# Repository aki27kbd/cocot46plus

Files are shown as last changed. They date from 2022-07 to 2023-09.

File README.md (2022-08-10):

# cocot46plus

cocot46plus_main15

cocot46plus is a column staggered keyboard with 46 keys, a 34mm-trackball and a rotary encoder.

- Keyboard Maintainer: [aki27kbd](https://github.com/aki27kbd) [@aki27kbd](https://twitter.com/aki27kbd)
- Hardware Supported: cocot46plus PCB, ProMicro
- Hardware Availability: [BOOTH](https://aki27.booth.pm/items/3879034)
  Go on sale in June 2022.

The detail information is available from the link below:  
[JP](https://www.notion.so/aki27/cocot46plus-55775bf44a664dae9d6ca342e79e8312) / [EN](https://aki27.notion.site/cocot46plus-Introduction-e6261b0a5ce045f8a0d8535a74844929)

[Firmware](https://github.com/aki27kbd/qmk_firmware/tree/master/keyboards/cocot46plus)

Build Guide [JP](doc/buildguide.md) / [EN](doc/buildguide_en.md)

### Special keycodes

Value    | Keycode   |Description
---------|-----------|-----------
`0x5DA7` | `CPI_SW`  |Switch CPI
`0x5DA8` | `SCRL_SW` |Switch scroll divider
`0x5DA9` | `ROT_R15` |Rotate sensor coordinate by 15 degrees clockwise
`0x5DAA` | `ROT_L15` |Rotate sensor coordinate by 15 degrees counterclockwise
`0x5DAB` | `SCRL_MO` |Enable scroll mode while being pressed
`0x5DAC` | `SCRL_TO` |Toggle scroll mode. Once pushed, mouse mode and scroll mode are switched.
`0x5DAD` | `SCRL_IN` |Invert scroll direction

### Gallery

cocot46plus_main12

cocot46plus_main14

cocot46plus_main05

cocot46plus_main02

cocot46plus_main10

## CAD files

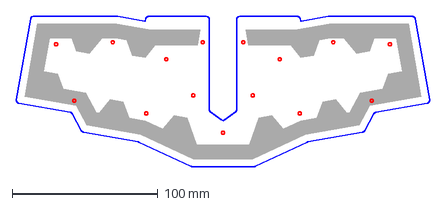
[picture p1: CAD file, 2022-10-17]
hardware/cocot46plus_acrylic_bottom.dxf
283.2 x 102.9 mm

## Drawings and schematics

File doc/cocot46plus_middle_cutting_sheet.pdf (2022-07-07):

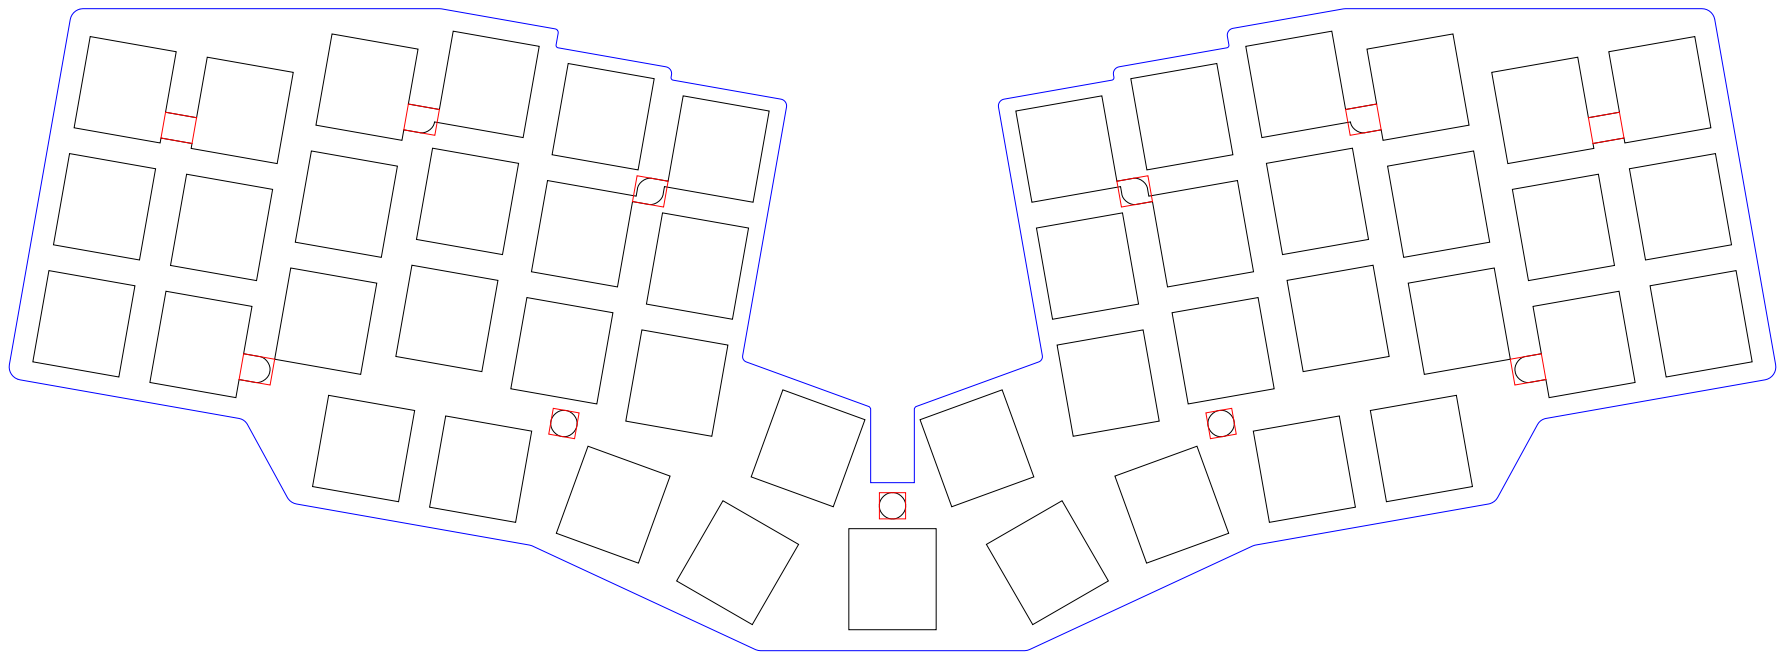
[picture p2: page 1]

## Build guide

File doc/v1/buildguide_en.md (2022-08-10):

# Build Guide

cocot46plus_main15

This is a build guide for cocot46plus.
One feature of cocot46plus is that it has a 34mm trackball in the center.
It also has a rotary encoder in the center between the thumb keys, allowing the encoder to be operated with both thumbs without disrupting the home position.
The OLED at the top can display current layer information and trackball status (CPI, rotary axis angle, etc.).
Other options include an acrylic laminated case, which can be mounted according to your preference.

## Parts
### Kit Accessories

|Switch_Plate|PCB PCB_v2|Bottom_Acryl|Bottom_FR4|
|---|---|---|---|
|Switch plate (FR4) x 1 piece|Pre-mounted PCB x 1 piece(may have tabs depending on the sales period)|Bottom plate➀ (Acrylic) x 1 piece(design may vary depending on the sales period)|Bottom plate➁ (FR4) x 1 piece|
|OLED_Cover|Spacer_8mm|Spacer_6mm|Spacer_3mm|
|OLED cover plate (FR4) x 1 piece|M2 spacer 8mm (female - female) x 15pcs|M2 spacer 6mm (female - female) x 4pcs|M2 spacer 3mm (female - male) x 4pcs|
|Screw_3mm|Screw_5mm|Screw_8mm|SwitchSocket|
|M2 Screw 3mm x 19pcs|M2 Screw 5mm x 15pcs|M2 Screw 8mm x 4pcs|Kailh MX Hotswap sockets x 46pcs|
|ADNS5050|SensorLED|OLED|ResetSwitch|
|Mouse sensor (ADNS-5050) and lens x 1 piece|LED for mouse sensor x 1 piece|OLED module, pin socket and pin header x 1 piece|Tact switch x 1 piece|
|RotaryEncoder|SK6812MINI-E|Rubber Feet||
|Rotary encoder (EC12 compatible) x 1 piece|RGB LED (SK6812MINI-E) x 2 pcs|Rubber feet x 6 pcs||

### Ball Case Accessories

|Ballcase_34mm|Ballcase_25mm|
|---|---|
|34mm ballcase (top and bottom) x 1 piece|25mm ballcase (top and bottom) and 25mm ball x 1 piece|

### Additional required parts

The following parts can be obtained from [Yousha Kobo](https://shop.yushakobo.jp/), [TALP KEYBOARD](https://talpkeyboard.net/), [Daily Craft Keyboard](https://shop.dailycraft.jp/), etc. 22mm diameter knobs are available at [Hechoamano Kobo @ Taneyatsu Branch](https://booth.pm/ja/items/3944829).

|Name|Number|Remarks|
|---|---|---|
|MicroUSB or USB-TypeC cable|1 piece||
|ProMicro or compatible microcontroller|1 piece||
|Header pins(2.5mm x 12pin)|2 pcs||
|46 switches|46pcs|MX compatible||
|46 keycaps (1U)|46pcs|MX compatible
|1 rotary encoder knob|1piece|22mm max. diameter or less
|34mm trackball|1piece|34mm ball case if selected|

*Sensor performance depends on the color of the trackball.  
*To improve the sensor performance of other ball colors a [modification](#Optional-mod) is available.  
*[Added on 8/8/2022] For boards with ver1.1 or later, [following mod](#Optional-mod) has already been implemented in default. The default performance is still the same, but the response of balls with darker colors such as green, black, etc. is also improved.

|Reactivity|Color|
|---|---|
|Good (smooth operation possible)|Red, Purple, Silver, Gold, Gray, Yellow, Pink, Lavender|
|Not good (The angle of the LED may make it a little less responsive, better to implement the modification)|Blue, Green||
|Worse (No response or stutter, need the modification)|Black|

### Optional parts (acrylic case)

Acrylic plates can be ordered with laser cutting services such as Yusha Kobo or Anymany for acrylic plates in your favorite colors.

Silicon sheets can be purchased from [here](https://www.monotaro.com/p/3629/5253/).

|Name|Number|Remarks|
|---|---|---|
|Acrylic middle plate (top)|1|for acrylic case
|Acrylic middle plate (bottom)|1|for acrylic case
|Silicon sheet 0.5mm thick|1|for acrylic case

## Assembly
### 0. Parts Check

  First, check that all the parts listed in the kit accessories are present.  
  Please prepare the kit with the above-mentioned "Additional required parts" and "optional parts" before starting the assembly.

  - If the PCB has tabs, break off the tabs and file the cut surface lightly.
  - Paint the sides of the PCB and switch plate black with an oil-based marker to make them look better. Please give it a try.

  Top: painted / Bottom: unpainted  
  cocot46plus_bg_00

### 1. Diodes

  Since ver1.0 or later, the diodes come pre-soldered on the board, so soldering the diodes is not necessary.

### Indicator LEDs

  Solder the indicator LEDs in two places beside the microcontroller. LEDs are very sensitive to heat, so set the soldering iron to a low temperature and wait long enough after soldering one pin before soldering the next.  
  At this stage, prepare the firmware described below and check the LEDs one by one as you solder, to confirm the leds are properly soldered at an early stage.
  With the default firmware, the indicator LEDs do not light up on the base layer. When checking the lighting, short the SW39 or SW44 pads with tweezers, to perform a layer switch and check the leds.

  cocot46plus_bg_02_1

  cocot46plus_bg_02_2

### 3. Underglow LED

  Since ver1.0 or later, the underglow LEDs come pre-soldered on the board, so soldering the underglow LEDs is not necessary.

### 4. Microcontroller

  Prepare the microcontroller. Solder the header pins in the orientation shown in the photo. In this case we are using spring loaded header pins. Note that these have an orientation. For more information about the direction of these pins, see [here](https://yushakobo.zendesk.com/hc/ja/articles/360044233974-%E3%82%B3%E3%83%B3%E3%82%B9%E3%83%AB%E3%83%BC-%E3%82%B9%E3%83%97%E3%83%AA%E3%83%B3%E3%82%B0%E3%83%94%E3%83%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)).  
  The USB Type-C version of a ProMicro is also supported. In case of micro USB, please reinforce the USB connector before soldering as it is prone to breaking off.

  cocot46plus_bg_04_1

### 5. mouse sensor

#### 5-1. ADNS-5050
  Place the mouse sensor (ADNS-5050) from the backside of the board in the orientation shown in the photo and solder from the topside.   
  ***Make sure to align the ●● mark on the silkscreen with the ●● mark on the board.***  
  cocot46plus_bg_05_1

  With the sensor legs firmly in place, secure them with masking tape or other means so that they stay in place.  
  cocot46plus_bg_05_2

  Solder the 8 legs from the topside.  
  cocot46plus_bg_05_3

  Remove the tape on the sensor, place the lens from the topside and fix it with masking tape, etc.  
  cocot46plus_bg_05_4

#### 5-2. Sensor LED

  Attach the LED for the mouse sensor. Pass the legs of the LED through the backside of the board. Pass the long leg through the round hole and the short leg through the square hole.  
  cocot46plus_bg_05_5

  Bend the LED legs 90 degrees and fix them with masking tape or similar so that they are positioned as shown in the photo below when viewed from the side.  
  cocot46plus_bg_05_5_2

  Solder two LED legs from the topside and trim the legs with flush cutters.  
  cocot46plus_bg_05_6

#### 5-3. Jumpers

  Bridge the pads on the back side of the board.
  cocot46plus_bg_05_7

  cocot46plus_bg_05_8

  Once you have completed this step, flash the firmware mentioned below and check the operation. If you have followed the steps correctly, a total of 12 LEDs and the LED for the mouse sensor should be lit.  
  ***The latest firmware supports LED1 & 2 as indicators. They are lit only when the layer is moved from the default.***
  cocot46plus_bg_05_9a

  Hold your hand in front of the lens on the top side and check if the mouse cursor is moving.  
  cocot46plus_bg_05_9b

### 6. MX sockets

  Solder the sockets on the back side of the PCB as shown in the picture. **Solder in all 46 locations**.

  cocot46plus_bg_06_1

### 7. OLED

  Insert the OLED pin socket from the front side and secure it with masking tape.  
  cocot46plus_bg_07_1

  cocot46plus_bg_07_2

  Solder the four pin socket legs from the backside of the board.  
  cocot46plus_bg_07_3

  Pass the pin headers through the OLED module and solder one by one so that they are not slanted.  
  cocot46plus_bg_07_4

### 8. Tact switch

  Insert the tact switch (reset switch) from the top side of the PCB and solder from the back side.  
  cocot46plus_bg_08_1

### 9. Rotary Encoder

  Solder the rotary encoder to the lower center section. Solder the rotary encoder from the back side.  
  cocot46plus_bg_09_1

  cocot46plus_bg_09_2

  All parts are finished being attached.  
  cocot46plus_bg_09_3

  cocot46plus_bg_09_4

### 10. Assembly

  To be updated.
  Secure the 8mm spacer to the bottom plate (acrylic) with 5mm screws.  
  cocot46plus_bg_10_1

  Place the bottom plate (FR4) over the back side (bottom side) of the acrylic plate and secure the 3mm spacer (female-male) with 5mm screws.  
  cocot46plus_bg_10_2

  Secure the 8mm spacer on the board with 3mm screws. Also insert the OLED into the pin socket.  
  cocot46plus_bg_10_3

  Place the switch plate and the board on top of each other and insert the key switches starting from the corners. Be careful to orient the switches and also make sure to insert them straight so that the switch legs do not bend.  
  cocot46plus_bg_10_4

  All keyswitches are inserted.  
  cocot46plus_bg_10_5

  Place the switch plate & board with the switches inserted on top of the bottom plate. Place 6mm spacers on the 4 places around the trackball.  
  cocot46plus_bg_10_6

  Secure the switch plate with 3mm screws.  
  cocot46plus_bg_10_7

  Secure the OLED cover plate with 3mm screws.  
  cocot46plus_bg_10_8

  Put the corresponding ball in the trackball case and secure it with 8mm screws.  
  cocot46plus_bg_10_9

  Attach the rubber feet to the bottom plate as shown.  
  cocot46plus_bg_10_10

  Put on the keycaps of your choice, a rotary encoder knob, and you're done!!!
  cocot46plus_bg_10_11

### 11. [Optional] Acrylic middle plate

  This section describes how to assemble the optional acrylic stacked case.
  Please prepare the following parts before assembling the acrylic case.

  |Name|Number|Remarks|
  |---|---|---|
  |1 Acrylic middle plate (top)|1|*1|
  |Acrylic middle plate (bottom)|1|*1|
  |1 silicon sheet 0.5mm thick|1|[click here](https://www.monotaro.com/p/3629/5253/)

  1 From Yuusha Kobo's acrylic plate service, [cocot46plus middle plate](https://shop.yushakobo.jp/collections/services/products/keyboard_acrylic_plate?variant=43940451746023) can be selected. Please select a color from here and place an order.  
  The original files can be found [here](https://github.com/aki27kbd/cocot46plus/blob/main/doc/cocot46plus_middle.zip?raw=true). Please use it when you want to create your own acrylic case.

  For cutting the silicone sheet, download the sheet from [here](https://github.com/aki27kbd/cocot46plus/blob/main/doc/cocot46plus_middle_cutting_sheet.pdf) and print it out at **100% scale**.
  Please note that if you print according to the file, the position of the key switch will be misaligned.
  Attach the silicon sheet with the protective sheet peeled off to the printed pattern paper. Since it is difficult to cut the screw part later, cut only the red part at this state. An exacto knife (30 degree blade) should be helpful here.

  After finishing cutting the red part, place the middle acrylic plate (top) on the silicon sheet so that the key switches are aligned, and cut the outer shape (blue line) and the key switch part (gray line).

  Layer the bottom plate, middle plate (bottom) PCB, middle plate (top), and switch plate in this order.

  Please refer to [Build Guide](https://github.com/aki27kbd/cocot46/blob/main/doc/buildguide.md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) of cocot46.

## Firmware

  You can download and flash the firmware to the microcontroller from [REMAP](https://remap-keys.app/catalog/JPk6Ey9xB6yrr5TDqoLh/firmware). The keymap can be updated from [HERE](https://remap-keys.app/configure).  
The above .hex file including trackballs and LEDs can be found here.

(You can also write the .hex file to the microcontroller using QMK Toolbox or other tools.)

REMAP

REMAP's Test Matrix Mode can be used to check if all keys are working as intended. However, since rotary encoder rotation cannot be checked in the Test Matrix Mode, please test the operation by key input, etc. separately.

In the standard firmware, the trackball movement is converted to scrolling in layers 1 and 2. If you want to change the layer for the scroll mode, please modify keymap.c.

See [here](https://github.com/aki27kbd/qmk_firmware/tree/master/keyboards/cocot46plus) for the source code.  
Also, please refer to [here](https://github.com/aki27kbd/cocot46plus/blob/main/firmware/cocot46plus_via.json) for the json file for VIA.

## Custom key codes

  It is possible to set several custom key codes for trackball operation.

  Value | Keycode |Description
  ---------|-----------|-----------
  `0x5DA7` | `CPI_SW`  |Changes the CPI of the trackball. The default firmware changes the CPI in the order 500 -> 750 -> 1000 -> 1250 -> 500... each time it is pressed.
  `0x5DA8` | `SCRL_SW` |Changes the sensitivity of the sensor in scroll mode. The higher the value, the smaller the amount of scrolling.
  `0x5DA9` | `ROT_R15` |Turns the Y axis of the mouse sensor 15 degrees clockwise.
  `0x5DAA` | `ROT_L15` |Rotate the Y axis of the mouse sensor 15 degrees counterclockwise.
  `0x5DAB` | `SCRL_MO` |Enables scroll mode for as long as it is pressed.
  `0x5DAC` |Toggles between scroll mode and mouse mode each time it is pressed.
  `0x5DAD` |Inverts the scroll direction.

  To set a custom key code in REMAP, enter the Value in the table above directly from CUSTOM as shown in the image below.

  CustomKeycode

## OLED

  OLED can display trackball information.  
  cocot46plus_bg_oled_1

  OLED|Description
  ---------|-----------
  Current Layer|Indicates the current layer.
  Scroll Status|Indicates C:Cursor/S:Scroll Mode.
  CPI|Indicates CPI in cursor mode.
  Scroll Divider|Indicates the sensitivity of the sensor in scroll mode. The higher the value, the smaller the scroll amount.
  Rotation Angle|This value indicates the rotation angle of the mouse sensor's Y axis.

  A comfortable Y-axis angle depends on the size of your hand and the way you place your hand on the trackball. Use the `ROT_R15` and `ROT_L15` keys to adjust it and find the setting that suits you best.  
  cocot46plus_bg_oled_2_2

  cocot46plus_bg_oled_3_4_5

## Optional mod

  **[Added on 8/8/2022] The boards after ver1.1 have these optional mods applied beforehand. The response of balls with darker colors such as green and black is also improved with the default.

  Ball colors that do not respond well in the default state will respond smoothly with a little modification.

  Attaching a smaller resistor to the R1 through-hole terminal on the backside of the PCB increases the brightness of the LED for the sensor and makes it react even with dark colored balls such as green and black.

  For reference, we have confirmed the operation of the Perix green bulb with [300Ω](https://akizukidenshi.com/catalog/g/gR-25301/) and the Perix black bulb with [150Ω](https://akizukidenshi.com/catalog/g/gR-25151/). We have confirmed that they work.

  cocot46plus_bg_mod_1

  cocot46plus_bg_mod_2

## Links

  [[Trackball] cocot46plus [Homemade keyboard]](https://www.youtube.com/watch?v=U7nu5G_PX5Y) (by Mr. Shiiba)  
  The site introduces the trackball, its internal structure, and compatible ball colors.

  [Gallery on Twitter](https://twitter.com/search?q=%23cocot46plus&src=typed_query&f=image)

## End

If you have any trouble, please contact us at our [Twitter account](https://twitter.com/aki27kbd).

Also, it would be very encouraging if you could upload photos of your work on social networking sites. (If you don't feel comfortable uploading your photos, you can send them directly to us via DM.)

The hashtag is #cocot46plus.

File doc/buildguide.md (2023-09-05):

# Build Guide

cocot46plus_main15

cocot46plusのビルドガイドになります。
cocot46plusは中央に34mmトラックボールを備えていることが一つの特徴です。
また親指キーの中央にロータリーエンコーダを配置しており、ホームポジションを崩すことなく両手の親指でエンコーダの操作が可能となっています。
中央奥側にはOLEDには現在のレイヤー情報、トラックボールのステータス（CPIや回転軸の角度など）を表示することができます。
その他オプションとしてアクリル積層ケースを用意しているので、お好みに合わせて実装ください。

v1のビルドガイドはこちら（[JP](v1/buildguide.md) / [EN](v1/buildguide_en.md)）を参照してください。

## 部品
### キット付属品

|Switch_Plate|PCB_v2|Bottom_Acryl_v2|Bottom_FR4|
|---|---|---|---|
|スイッチプレート（FR4）×1枚|実装済基板×1枚|ボトムプレート➀（アクリル）×1枚（販売時期によってデザインが異なる場合があります）|ボトムプレート➁（FR4）×1枚|
|OLED_Cover|Spacer_8mm_v2|Spacer_3mm_FF|Screw_3mm|
|OLEDカバープレート（FR4）×1枚|M2 スペーサー 長（メス―メス）×15本|M2 スペーサー 短（メス―メス）×4本|M2 ねじ 短×19本|
|Screw_5.5mm|Screw_8mm|ProMicro|Spring_Pin_Header|
|M2 ねじ 中×15本|M2 ねじ 長×4本|ProMicro×1個|コンスル―×2本|
|ADNS5050|OLED|ResetSwitch|ゴム足|
|マウスセンサー（ADNS-5050）・レンズ×各1個|OLEDモジュール・ピンソケット・ピンヘッダ×各1個|タクトスイッチ×1個|ゴム脚×6個|
|RotaryEncoder|SK6812MINI-E|Ballcase_34mm_v2||
|ロータリーエンコーダ（EC12互換）×1個|ノブ×1個|ボールケース×1個（＋セラミックボール×3個）||

### キット以外に必要なもの

下記パーツは[遊舎工房](https://shop.yushakobo.jp/)、[TALP KEYBOARD](https://talpkeyboard.net/)、[Daily Craft Keyboard](https://shop.dailycraft.jp/)などで揃えることが可能です。また、22mm径ノブは[へちょあまの工房＠たねやつ支店](https://booth.pm/ja/items/3944829)での品揃えが豊富です。

|名前|数|備考|
|---|---|---|
|USB-TypeCケーブル|1本||
|キースイッチ|46個|MX互換|
|キーキャップ（1U）|46個|MX互換|
|34mmボール|1個||

各ショップの在庫状況に応じて検討ください。

### オプション部品（アクリル積層ケース）

アクリルは遊舎工房やAnymanyなどのレーザーカットサービスでお好きな色のアクリルプレートを発注することが可能です。

シリコンシートは[こちら](https://www.monotaro.com/p/3629/5253/)から購入可能です。

|名前|数|備考|
|---|---|---|
|アクリルミドルプレート（上）|1枚|アクリル積層ケース用|
|アクリルミドルプレート（下）|1枚|アクリル積層ケース用|
|シリコンシート厚さ0.5mm|1枚|アクリル積層ケース用|

## 組み立て
### 0. 部品確認

  まずはキット付属品に記載されたパーツが揃っているか確認ください。  
  その他上述の「キット以外に必要なもの」および「オプション部品」を揃えた上で組み立てに取り掛かってください。

  - タブ付きPCBの場合にはタブを割って切り離し、切断面を軽くヤスリがけしてください。
  - PCB、スイッチプレートの側面を油性マジックなどで黒く塗ると見栄えが良くなります。ぜひ試してみてください。

  上:塗装済み / 下:未塗装  
  cocot46plus_bg_00

### 1. ProMicro

  ProMicroの準備をします。写真の向きでコンスル―をはんだ付けします。  
  コンスル―には向きがあるので注意してください。コンスル―の向きについては[こちら](https://yushakobo.zendesk.com/hc/ja/articles/360044233974-%E3%82%B3%E3%83%B3%E3%82%B9%E3%83%AB%E3%83%BC-%E3%82%B9%E3%83%97%E3%83%AA%E3%83%B3%E3%82%B0%E3%83%94%E3%83%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)を参照ださい。  
  遊舎工房で販売のキットにはマイクロUSB版が付属していますが、USB Type-C版のProMicroにも対応しています。マイクロUSBの場合、USBコネクタがもげやすいので、適宜補強をしてからはんだ付けを行ってください。
  **Elite-Cには対応していません。ご注意ください。**

  cocot46plus_bg_01_1

### 2. マウスセンサー（ADNS-5050）

  マウスセンサー（ADNS-5050）を基板裏面から写真の向きに設置し、表面からはんだ付けを行います。シルクの●●印と基板の●●印の位置が合うように注意してください。  
  cocot46plus_bg_02_1

  センサーの脚がしっかり奥まで入った状態で、浮かないようにマスキングテープなどで固定します。  
  cocot46plus_bg_02_2

  表面から8本の脚をはんだ付けします。センサーに貼られているテープもこのタイミングではがしておきます。  
  テープをはがしたらセンサーを取り付け、マスキングテープなどで軽く固定しておきます。
  cocot46plus_bg_02_3

### 3. OLED

  OLEDピンソケットを表側から挿し、マスキングテープなどで固定します。  
  cocot46plus_bg_03_1

  cocot46plus_bg_03_2

  基板裏側からピンソケットの脚4本のはんだ付けを行ってください。  
  cocot46plus_bg_03_3

  OLEDモジュールにピンヘッダを通し、斜めにならないように1本ずつはんだ付けを行います。  
  cocot46plus_bg_03_4

### 4. タクトスイッチ

  PCB表面に、タクトスイッチ（リセットスイッチ）を取り付け、裏面からはんだ付けします。1箇所のみです。  
  cocot46plus_bg_04_1

### 5. ロータリーエンコーダ

  中央部分にロータリーエンコーダをはんだ付けします。ロータリーエンコーダの脚を通し、裏側からはんだ付けをしてください。  
  cocot46plus_bg_05_1

  cocot46plus_bg_05_2

  全てのパーツを付け終わった状態です。  
  cocot46plus_bg_09_3

  cocot46plus_bg_09_4

### 6. ボールケース

  ボールケースにセラミックボールを固定します。キット内容物以外に必要な道具は下記写真の通り、エポキシ2液混合接着剤、接着剤を取り出す容器、爪楊枝になります。  
  cocot46plus_bg_ballcase_01

  接着剤の取り扱い説明に沿って接着液の準備を行います。  
  cocot46plus_bg_ballcase_02

  爪楊枝の先端に接着剤を少量付け、ボールケース内側の穴に塗ります。塗りすぎるとボールを嵌めた際にあふれてしまうので、窪みの内側が接着剤で薄く覆われる程度を目安としてください。  
  cocot46plus_bg_ballcase_03

  cocot46plus_bg_ballcase_04

  接着剤が乾く前にボールをはめ込みます。接着剤がボールの周りにあふれてしまった場合は固まる前にきれいにふき取ってください。  
  cocot46plus_bg_ballcase_05

  3箇所すべてボールを接着すればボールケースの準備完了です。  
  cocot46plus_bg_ballcase_06

### 7. 組み立て

  ボトムプレート（アクリル）にネジ（中）でスペーサー（長）を固定します。  
  cocot46plus_bg_06_1

  ボトムプレート（FR4）をアクリルの裏側（底側）に重ね、ネジ（中）でスペーサー（短）を固定します。  
  cocot46plus_bg_06_2

  基板上にネジ（短）でスペーサー（長）を固定します。またOLEDもピンソケットに差し込んでおきます。  
  cocot46plus_bg_06_3

  スイッチプレートと基板を重ね、隅から順番にキースイッチをはめていきます。スイッチの向きに気を付けて、またスイッチの脚が曲がらないように真っすぐに差し込むようにしてください。  
  cocot46plus_bg_06_4

  全てのキースイッチを差し込んだ状態です。  
  cocot46plus_bg_06_5

  スイッチプレートをネジ（短）で固定します。  
  cocot46plus_bg_06_6

  OLEDカバープレートをネジ（短）で固定します。  
  cocot46plus_bg_06_7

  トラックボールケースに対応するボールを入れ、ネジ（長）で固定します。  
  レンズを仮固定していたマスキングテープはこのタイミングではがしてください。
  cocot46plus_bg_06_8

  ボトムプレートにバランスよくゴム脚を貼り付けます。  
  cocot46plus_bg_06_9

  お好みのキーキャップ、ロータリーエンコーダのノブを付けて完成です！
  cocot46plus_bg_06_10

### 11. [オプション]アクリルミドルプレート

  オプションであるアクリル積層ケースの組み立て方についてです。
  下記パーツを揃えた上で積層ケースの組み立てにのぞんでください。

  |名前|数|備考|
  |---|---|---|
  |アクリルミドルプレート（上）|1枚|※1|
  |アクリルミドルプレート（下）|1枚|※1|
  |シリコンシート 厚さ0.5mm|1枚|[こちら](https://www.monotaro.com/p/3629/5253/)から購入可能|

  ※1 遊舎工房のアクリルプレートサービスより、[cocot46plusのミドルプレート](https://shop.yushakobo.jp/collections/services/products/keyboard_acrylic_plate?variant=43940451746023)が選択できるようになりました。こちらからアクリルカラーを選択して発注してください。  
  元データは[こちら](https://github.com/aki27kbd/cocot46plus/blob/main/doc/cocot46plus_middle.zip?raw=true)にあります。オリジナルの積層ケースを作成したい場合などに用いてください。

  シリコンシートのカッティング補助用に、[こちら](https://github.com/aki27kbd/cocot46plus/blob/main/doc/cocot46plus_middle_cutting_sheet.pdf)のシートをダウンロードし、**拡大率100%** で印刷してください。用紙に合わせて印刷してしまうとキースイッチの位置がずれてしまうのでご注意ください。
  印刷した型紙に、保護シートをはがしたシリコンシートを貼り付けます。ねじ部分は後からカットすることが難しいので、この状態で赤い部分のみカットしておきます。デザインナイフやカッターナイフ（30度刃）がカットしやすいと思います。

  赤い部分をカットし終わったら、キースイッチの位置が合うようにミドルアクリルプレート（上）をシリコンシートの上に置き、外形（青線）とキースイッチ部分（灰色線）をカットしていきます。

  ボトムプレート、ミドルプレート（下）PCB、ミドルプレート（上）、スイッチプレートの順に重ねます。

  cocot46の[ビルドガイド](https://github.com/aki27kbd/cocot46/blob/main/doc/buildguide.md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)も参考に組み立ててみてください。

## ファームウェア

  [REMAP](https://remap-keys.app/catalog/JPk6Ey9xB6yrr5TDqoLh/firmware)からファームウェアのダウンロードおよびProMicroへの書き込みを行うことができます。キーマップは[こちら](https://remap-keys.app/configure)から更新可能です。  
トラックボール、LED含めて上記.hexファイルで確認いただけます。

（.hexファイルをQMK ToolboxなどでProMicroに書き込む従来の方法でも問題ありません。）

REMAP

組み立て段階で動作確認をする際も、REMAPのTest Matrix Modeを使うと便利です。ただし、Test Matrix Modeではロータリーエンコーダの回転は確認できないので、別途キー入力等で動作を試してください。

標準ファームウェアでは、レイヤー1と2でトラックボールの動きがスクロールに変換されるようになっています。スクロールモードになるレイヤーを変更したい場合は、keymap.cを修正してください。

ソースコードは[こちら](https://github.com/aki27kbd/qmk_firmware/tree/master/keyboards/aki27/cocot46plus)を参照ください。  
また、VIA用のjsonファイルは[こちら](https://github.com/aki27kbd/cocot46plus/blob/main/firmware/cocot46plus_via.json)を参照ください。

## カスタムキーコード

  トラックボールの操作に関していくつかカスタムキーコードを設定することが可能です。

  Value    | Keycode   |Description
  ---------|-----------|-----------
  `0x5DA7` | `CPI_SW`  |トラックボールのCPIを変更します。デフォルトのファームウェアでは、押すたびに500→750→1000→1250→500…という順番でCPIが変わります。
  `0x5DA8` | `SCRL_SW` |スクロールモードにおけるセンサーの感度を変更します。数値が大きいほどスクロール量が小さくなります。
  `0x5DA9` | `ROT_R15` |マウスセンサーのＹ軸を時計回りに15度回転させます。
  `0x5DAA` | `ROT_L15` |マウスセンサーのＹ軸を反時計回りに15度回転させます。
  `0x5DAB` | `SCRL_MO` |押されている間スクロールモードになります。
  `0x5DAC` | `SCRL_TO` |押すたびにスクロールモードとマウスモードを切り替えます。
  `0x5DAD` | `SCRL_IN` |スクロール方向を反転させます。

  REMAPでカスタムキーコードを設定する場合は下記の画面からカスタムキーコードを設定可能です。
  CustomKeycode_rev

## OLED

  OLEDにはトラックボールの情報を表示することが可能です。  
  cocot46plus_bg_oled_1

  OLED|Description
  ---------|-----------
  Current Layer|現在のレイヤーを示します。
  Scroll Status|C:カーソル/S:スクロールモードを示します。
  CPI|カーソルモードのCPIを示します。
  Scroll Divider|スクロールモードにおけるセンサーの感度を示します。数値が大きいほどスクロール量が小さくなります。
  Rotation Angle|マウスセンサーのY軸の回転角を示します。

  手の大きさやトラックボールへの手の置き方によって、操作しやすいY軸の回転角が異なります。`ROT_R15`、`ROT_L15`キーで調整しながら自分に合った設定を探してみてください。  
  cocot46plus_bg_oled_2_2

  cocot46plus_bg_oled_3_4_5

## Links

  [【トラックボール】cocot46plus【自作キーボード】](https://www.youtube.com/watch?v=U7nu5G_PX5Y) (by 椎葉さん)  
  トラックボールの使い心地、内部構造、適合するボール色など紹介いただいています。

  [Gallery on Twitter](https://twitter.com/search?q=%23cocot46plus&src=typed_query&f=image)

## 終わりに
何かトラブルがあれば[Twitterアカウント](https://twitter.com/aki27kbd)までご連絡ください。

また、完成写真をSNSにアップいただけるととても励みになります。（アップするのがはばかられる方はDMで直接送りつけていただいても構いません。）

ハッシュタグは #cocot46plus です。

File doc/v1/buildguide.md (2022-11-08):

# Build Guide

cocot46plus_main15

cocot46plusのビルドガイドになります。
cocot46plusは中央に34mmトラックボールを備えていることが一つの特徴です。
また親指キーの中央にロータリーエンコーダを配置しており、ホームポジションを崩すことなく両手の親指でエンコーダの操作が可能となっています。
中央奥側にはOLEDには現在のレイヤー情報、トラックボールのステータス（CPIや回転軸の角度など）を表示することができます。
その他オプションとしてアクリル積層ケースを用意しているので、お好みに合わせて実装ください。

## 部品
### キット付属品

|Switch_Plate|PCB PCB_v2|Bottom_Acryl|Bottom_FR4|
|---|---|---|---|
|スイッチプレート（FR4）×1枚|実装済基板×1枚（販売時期によってタブがついている場合があります）|ボトムプレート➀（アクリル）×1枚（販売時期によってデザインが異なる場合があります）|ボトムプレート➁（FR4）×1枚|
|OLED_Cover|Spacer_8mm|Spacer_6mm|Spacer_3mm|
|OLEDカバープレート（FR4）×1枚|M2 スペーサー 8mm（メス―メス）×15本|M2 スペーサー 6mm（メス―メス）×4本|M2 スペーサー 3mm（メス―オス）×4本|
|Screw_3mm|Screw_5mm|Screw_8mm|SwitchSocket|
|M2 ねじ 3mm×19本|M2 ねじ 5mm×15本|M2 ねじ 8mm×4本|MX互換スイッチ用PCBソケット×46個|
|ADNS5050|SensorLED|OLED|ResetSwitch|
|マウスセンサー（ADNS-5050）・レンズ×各1個|マウスセンサー用LED×1個|OLEDモジュール・ピンソケット・ピンヘッダ×各1個|タクトスイッチ×1個|
|RotaryEncoder|SK6812MINI-E|ゴム足||
|ロータリーエンコーダ（EC12互換）×1個|フルカラーシリアルLED (SK6812MINI-E)×2個|ゴム足×6個||

### ボールケース付属品

|Ballcase_34mm|Ballcase_25mm|
|---|---|
|34mmボールケース（上・下）×1個|25mmボールケース（上・下）・25mmボール×1個|

### キット以外に必要なもの

下記パーツは[遊舎工房](https://shop.yushakobo.jp/)、[TALP KEYBOARD](https://talpkeyboard.net/)、[Daily Craft Keyboard](https://shop.dailycraft.jp/)などで揃えることが可能です。また、22mm径ノブは[へちょあまの工房＠たねやつ支店](https://booth.pm/ja/items/3944829)での品揃えが豊富です。

|名前|数|備考|
|---|---|---|
|MicroUSB or USB-TypeCケーブル|1本||
|ProMicro|1個||
|コンスル―（2.5mm×12ピン）|2本||
|キースイッチ|46個|MX互換|
|キーキャップ（1U）|46個|MX互換|
|ロータリーエンコーダ用ノブ|1個|最大直径22mm以下|
|34mmボール|1個|34mmボールケースを選択した場合|

各ショップの在庫状況に応じて検討ください。

<details>
<summary>ver1.0でのボール色による反応について</summary>
※ver1.0基板では、34mmボールの色に応じてセンサーの反応が悪くなる場合があります。  
※デフォルトで反応の悪いボール色も後述の[オプションMOD](https://github.com/aki27kbd/cocot46plus/blob/main/doc/buildguide.md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)を施すことで、スムーズに反応するようになります。
※[2022/8/8追記] ver1.1以降の基板では、予め[オプションMOD](https://github.com/aki27kbd/cocot46plus/blob/main/doc/buildguide.md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)が施された状態になっています。デフォルトのままでグリーン、ブラックなどの暗い色のボールの反応も改善されています。

|反応性|色|
|---|---|
|〇（スムーズに動作可能）|レッド、パープル、シルバー、ゴールド、グレー、イエロー、ピンク、ラベンダー|
|△（LEDの角度によって少し反応が悪くなる場合あり）|ブルー、グリーン|
|×（反応しないorカクつく）|ブラック|

</details>

### オプション部品（アクリル積層ケース）

アクリルは遊舎工房やAnymanyなどのレーザーカットサービスでお好きな色のアクリルプレートを発注することが可能です。

シリコンシートは[こちら](https://www.monotaro.com/p/3629/5253/)から購入可能です。

|名前|数|備考|
|---|---|---|
|アクリルミドルプレート（上）|1枚|アクリル積層ケース用|
|アクリルミドルプレート（下）|1枚|アクリル積層ケース用|
|シリコンシート厚さ0.5mm|1枚|アクリル積層ケース用|

## 組み立て
### 0. 部品確認

  まずはキット付属品に記載されたパーツが揃っているか確認ください。  
  その他上述の「キット以外に必要なもの」および「オプション部品」を揃えた上で組み立てに取り掛かってください。

  - タブ付きPCBの場合にはタブを割って切り離し、切断面を軽くヤスリがけしてください。
  - PCB、スイッチプレートの側面を油性マジックなどで黒く塗ると見栄えが良くなります。ぜひ試してみてください。

  上:塗装済み / 下:未塗装  
  cocot46plus_bg_00

### 1. ダイオード

  ver1.0以降は予め基板にはんだ付けされているので、ダイオードのはんだ付けは不要です。

### 2. インジケータLED

  ProMicro横の2箇所にインジケータLEDのはんだ付けを行います。4箇所あるパッドの1箇所に予備はんだを盛り、LEDの位置を固定します。PCBのシルク上の角の部分と、LEDの三角に欠けている部分の向きが揃うようにはんだ付けしてください。LEDは非常に熱に弱いので、はんだごての温度を低めに設定し、一か所はんだ付けをしたら十分時間をおいてから次のはんだ付けを行いましょう。  
  この段階で後述のファームウェアを準備し、LEDの点灯を一つずつ確認しながらはんだ付けを行うとミスの早期発見につながります。
  ※デフォルトのファームウェアでは、レイヤー0ではインジケータLEDが点灯しません。点灯確認の際はSW39もしくはSW44のパッドをピンセットなどで短絡させ、レイヤー移動した状態で確認ください。

  cocot46plus_bg_02_1

  cocot46plus_bg_02_2

### 3. アンダーグロウLED

  ver1.0以降は予め基板にはんだ付けされているので、アンダーグロウLEDのはんだ付けは不要です。

### 4. ProMicro

  ProMicroの準備をします。写真の向きでコンスル―をはんだ付けします。  
  コンスル―には向きがあるので注意してください。コンスル―の向きについては[こちら](https://yushakobo.zendesk.com/hc/ja/articles/360044233974-%E3%82%B3%E3%83%B3%E3%82%B9%E3%83%AB%E3%83%BC-%E3%82%B9%E3%83%97%E3%83%AA%E3%83%B3%E3%82%B0%E3%83%94%E3%83%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)を参照ださい。  
  USB Type-C版のProMicroにも対応しています。マイクロUSBの場合、USBコネクタがもげやすいので、適宜補強をしてからはんだ付けを行ってください。

  cocot46plus_bg_04_1

### 5. マウスセンサー

#### 5-1. ADNS-5050
  マウスセンサー（ADNS-5050）を基板裏面から写真の向きに設置し、表面からはんだ付けを行います。シルクの●●印と基板の●●印の位置が合うように注意してください。  
  cocot46plus_bg_05_1

  センサーの脚がしっかり奥まで入った状態で、浮かないようにマスキングテープなどで固定します。  
  cocot46plus_bg_05_2

  表面から8本の脚をはんだ付けします。  
  cocot46plus_bg_05_3

  センサーに貼られているテープを剥がし、表面からレンズを付けてマスキングテープなどで固定します。  
  cocot46plus_bg_05_4

#### 5-2. センサー用LED

  マウスセンサー用LEDを取り付けます。基板裏面からLEDの脚を通します。脚の長い方を丸い穴、短い方を四角い穴に通します。  
  cocot46plus_bg_05_5

  LEDの脚を90度曲げ、横から見た時に下の写真のような位置関係になるようにマスキングテープなどで固定します。  
  cocot46plus_bg_05_5_2

  表面からLEDの脚を2箇所はんだ付けし、余分な脚をカットします。  
  cocot46plus_bg_05_6

#### 5-3. ジャンパー

  基板裏面のジャンパーの両側のパッドにはんだを盛り、ブリッジさせます。  
  cocot46plus_bg_05_7

  cocot46plus_bg_05_8

  ここまでの作業が完了したら、ProMicroに後述のファームウェアを書き込み、動作確認を行いましょう。正しい手順を踏めている場合、全部で12個のLEDとマウスセンサー用LEDが点灯しているはずです。  
  cocot46plus_bg_05_9a

  表面のレンズの前に手をかざし、マウスカーソルが動いているか確認してみてください。  
  cocot46plus_bg_05_9b

### 6. MXソケット

  PCB裏面に、写真の向きでソケットをはんだ付けします。**全46箇所**はんだ付けを行ってください。

  cocot46plus_bg_06_1

### 7. OLED

  OLEDピンソケットを表側から挿し、マスキングテープなどで固定します。  
  cocot46plus_bg_07_1

  cocot46plus_bg_07_2

  基板裏側からピンソケットの脚4本のはんだ付けを行ってください。  
  cocot46plus_bg_07_3

  OLEDモジュールにピンヘッダを通し、斜めにならないように1本ずつはんだ付けを行います。  
  cocot46plus_bg_07_4

### 8. タクトスイッチ

  PCB表面に、タクトスイッチ（リセットスイッチ）を取り付け、裏面からはんだ付けします。1箇所のみです。  
  cocot46plus_bg_08_1

### 9. ロータリーエンコーダ

  中央部分にロータリーエンコーダをはんだ付けします。ロータリーエンコーダの脚を通し、裏側からはんだ付けをしてください。  
  cocot46plus_bg_09_1

  cocot46plus_bg_09_2

  全てのパーツを付け終わった状態です。  
  cocot46plus_bg_09_3

  cocot46plus_bg_09_4

### 10. 組み立て

  To be updated.
  ボトムプレート（アクリル）に5mmネジで8mmスペーサーを固定します。  
  cocot46plus_bg_10_1

  ボトムプレート（FR4）をアクリルの裏側（底側）に重ね、5mmネジで3mmスペーサー（メス―オス）を固定します。  
  cocot46plus_bg_10_2

  基板上に3mmネジで8mmスペーサーを固定します。またOLEDもピンソケットに差し込んでおきます。  
  cocot46plus_bg_10_3

  スイッチプレートと基板を重ね、隅から順番にキースイッチをはめていきます。スイッチの向きに気を付けて、またスイッチの脚が曲がらないように真っすぐに差し込むようにしてください。  
  cocot46plus_bg_10_4

  全てのキースイッチを差し込んだ状態です。  
  cocot46plus_bg_10_5

  スイッチを差し込んだスイッチプレート&基板を、ボトムプレートの上に重ねます。トラックボール廻りの4箇所を6mmスペーサーで固定します。  
  cocot46plus_bg_10_6

  スイッチプレートを3mmネジで固定します。  
  cocot46plus_bg_10_7

  OLEDカバープレートを3mmネジで固定します。  
  cocot46plus_bg_10_8

  トラックボールケースに対応するボールを入れ、8mmネジで固定します。  
  cocot46plus_bg_10_9

  ボトムプレートにバランスよくゴム脚を貼り付けます。  
  cocot46plus_bg_10_10

  お好みのキーキャップ、ロータリーエンコーダのノブを付けて完成です！
  cocot46plus_bg_10_11

### 11. [オプション]アクリルミドルプレート

  オプションであるアクリル積層ケースの組み立て方についてです。
  下記パーツを揃えた上で積層ケースの組み立てにのぞんでください。

  |名前|数|備考|
  |---|---|---|
  |アクリルミドルプレート（上）|1枚|※1|
  |アクリルミドルプレート（下）|1枚|※1|
  |シリコンシート 厚さ0.5mm|1枚|[こちら](https://www.monotaro.com/p/3629/5253/)から購入可能|

  ※1 遊舎工房のアクリルプレートサービスより、[cocot46plusのミドルプレート](https://shop.yushakobo.jp/collections/services/products/keyboard_acrylic_plate?variant=43940451746023)が選択できるようになりました。こちらからアクリルカラーを選択して発注してください。  
  元データは[こちら](https://github.com/aki27kbd/cocot46plus/blob/main/doc/cocot46plus_middle.zip?raw=true)にあります。オリジナルの積層ケースを作成したい場合などに用いてください。

  シリコンシートのカッティング補助用に、[こちら](https://github.com/aki27kbd/cocot46plus/blob/main/doc/cocot46plus_middle_cutting_sheet.pdf)のシートをダウンロードし、**拡大率100%** で印刷してください。用紙に合わせて印刷してしまうとキースイッチの位置がずれてしまうのでご注意ください。
  印刷した型紙に、保護シートをはがしたシリコンシートを貼り付けます。ねじ部分は後からカットすることが難しいので、この状態で赤い部分のみカットしておきます。デザインナイフやカッターナイフ（30度刃）がカットしやすいと思います。

  赤い部分をカットし終わったら、キースイッチの位置が合うようにミドルアクリルプレート（上）をシリコンシートの上に置き、外形（青線）とキースイッチ部分（灰色線）をカットしていきます。

  ボトムプレート、ミドルプレート（下）PCB、ミドルプレート（上）、スイッチプレートの順に重ねます。

  cocot46の[ビルドガイド](https://github.com/aki27kbd/cocot46/blob/main/doc/buildguide.md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)も参考に組み立ててみてください。

## ファームウェア

  [REMAP](https://remap-keys.app/catalog/JPk6Ey9xB6yrr5TDqoLh/firmware)からファームウェアのダウンロードおよびProMicroへの書き込みを行うことができます。キーマップは[こちら](https://remap-keys.app/configure)から更新可能です。  
トラックボール、LED含めて上記.hexファイルで確認いただけます。

（.hexファイルをQMK ToolboxなどでProMicroに書き込む従来の方法でも問題ありません。）

REMAP

組み立て段階で動作確認をする際も、REMAPのTest Matrix Modeを使うと便利です。ただし、Test Matrix Modeではロータリーエンコーダの回転は確認できないので、別途キー入力等で動作を試してください。

標準ファームウェアでは、レイヤー1と2でトラックボールの動きがスクロールに変換されるようになっています。スクロールモードになるレイヤーを変更したい場合は、keymap.cを修正してください。

ソースコードは[こちら](https://github.com/aki27kbd/qmk_firmware/tree/master/keyboards/aki27/cocot46plus)を参照ください。  
また、VIA用のjsonファイルは[こちら](https://github.com/aki27kbd/cocot46plus/blob/main/firmware/cocot46plus_via.json)を参照ください。

## カスタムキーコード

  トラックボールの操作に関していくつかカスタムキーコードを設定することが可能です。

  Value    | Keycode   |Description
  ---------|-----------|-----------
  `0x5DA7` | `CPI_SW`  |トラックボールのCPIを変更します。デフォルトのファームウェアでは、押すたびに500→750→1000→1250→500…という順番でCPIが変わります。
  `0x5DA8` | `SCRL_SW` |スクロールモードにおけるセンサーの感度を変更します。数値が大きいほどスクロール量が小さくなります。
  `0x5DA9` | `ROT_R15` |マウスセンサーのＹ軸を時計回りに15度回転させます。
  `0x5DAA` | `ROT_L15` |マウスセンサーのＹ軸を反時計回りに15度回転させます。
  `0x5DAB` | `SCRL_MO` |押されている間スクロールモードになります。
  `0x5DAC` | `SCRL_TO` |押すたびにスクロールモードとマウスモードを切り替えます。
  `0x5DAD` | `SCRL_IN` |スクロール方向を反転させます。

  REMAPでカスタムキーコードを設定する場合は下記の画面のようにCUSTOMから上の表のValueを直接入力してください。

  CustomKeycode

  ※[2022/11/8追記] 最新の[ファームウェア](https://remap-keys.app/catalog/JPk6Ey9xB6yrr5TDqoLh/firmware)を書き込むと、RemapからValueを直接入力することなくカスタムキーコードを入力できるようになりました。
  CustomKeycode_rev

## OLED

  OLEDにはトラックボールの情報を表示することが可能です。  
  cocot46plus_bg_oled_1

  OLED|Description
  ---------|-----------
  Current Layer|現在のレイヤーを示します。
  Scroll Status|C:カーソル/S:スクロールモードを示します。
  CPI|カーソルモードのCPIを示します。
  Scroll Divider|スクロールモードにおけるセンサーの感度を示します。数値が大きいほどスクロール量が小さくなります。
  Rotation Angle|マウスセンサーのY軸の回転角を示します。

  手の大きさやトラックボールへの手の置き方によって、操作しやすいY軸の回転角が異なります。`ROT_R15`、`ROT_L15`キーで調整しながら自分に合った設定を探してみてください。  
  cocot46plus_bg_oled_2_2

  cocot46plus_bg_oled_3_4_5

## オプションMOD

  ※※[2022/8/8追記] ver1.1以降の基板では、予めこちらのオプションMODが施された状態になっています。デフォルトのままでグリーン、ブラックなどの暗い色のボールの反応も改善されています。

  <details>
<summary>オプションMOD</summary>

  ver1.0基板のデフォルトの状態では反応の悪いボール色も、少し手を加えることでスムーズに反応するようになります。

  PCB裏面のR1のスルーホール端子部分に小さめの抵抗を付けることでセンサー用LEDの明るさが増し、緑や黒などの暗い色の球でも反応するようになります。

  参考までに、ぺリックス緑球は[300Ω](https://akizukidenshi.com/catalog/g/gR-25301/)、ぺリックス黒球は[150Ω](https://akizukidenshi.com/catalog/g/gR-25151/)で動作確認できています。

  cocot46plus_bg_mod_1

  cocot46plus_bg_mod_2

  </details>

## Links

  [【トラックボール】cocot46plus【自作キーボード】](https://www.youtube.com/watch?v=U7nu5G_PX5Y) (by 椎葉さん)  
  トラックボールの使い心地、内部構造、適合するボール色など紹介いただいています。

  [Gallery on Twitter](https://twitter.com/search?q=%23cocot46plus&src=typed_query&f=image)

## 終わりに
何かトラブルがあれば[Twitterアカウント](https://twitter.com/aki27kbd)までご連絡ください。

また、完成写真をSNSにアップいただけるととても励みになります。（アップするのがはばかられる方はDMで直接送りつけていただいても構いません。）

ハッシュタグは #cocot46plus です。

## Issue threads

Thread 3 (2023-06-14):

Updated QMK Firmware link/hex?

nickdepinet, 2023-06-14:
Hi,

Built a cocot46plus from yushakobo sale. Used usb-c pro-micro ATmega32U4 with DFU bootloader, so need firmware. Tried to compile firmware from https://github.com/aki27kbd/qmk_firmware/tree/master/keyboards/aki27/cocot46plus using qmk_msys with `qmk compile -kb aki27/cocot46plus -km default`, but there are a bunch of compile errors on defines.  Is there an updated firmware somewhere that compiles for pro-micro? or a HEX file? VIA doesn't recognize the keyboard without firmware.

rabanesEP, 2023-07-02:
Hello,

I've tried compiling using said method and came up with the same problems (but using a pro-micro). If you arent't able to flash the firmware until now, I recommend using the firmware (hex file) from remap (https://remap-keys.app/catalog/JPk6Ey9xB6yrr5TDqoLh). I flashed mine using avrdude as the ttyACM* keeps on changing, but I believe you could use the online app itself.

markstos, 2025-05-31:
@nickdepinet There's a completely updated firmware here.

https://github.com/qmk/qmk_firmware/pull/23892

I started working on it with a pro-micro, but it was difficult or impossible to support the trackball, LED, underglow and RGB lights all in that memory, so I switched to an RP2040.  I believe I'm using this replacement for the pro-micro:

https://www.sparkfun.com/sparkfun-pro-micro-rp2040.html

The working code is here: https://github.com/qmk/qmk_firmware/pull/23892 and should hopefully be officially merged into the QMK repo soon.

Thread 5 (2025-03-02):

Cannot customize keys with Remap

yoichi, 2025-03-02:
When I select cocot46plus at https://remap-keys.app/configure, the message "Opening keyboard" remains displayed and I cannot proceed to the keymap editing screen.

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

The problem occur with the latest firmware:
cocot46plus_default (January 20th 2025, 08:48:58 | SHA256: a6329de93551a9650175921a4e4310c94ec653e3f848a65c780e9f0843978262)

The problem doesn't occur with
cocot46plus_default_22_3 (October 9th 2023, 14:05:02 | SHA256: 8132363bbdfa99ce4e6e1ac316a20867894509202ead442a5e904de2756937c9)

yoichi, 2025-03-02:
I found a workaround, but I'm not sure if this is a qmk_firmware issue or a remapping issue.

```
diff --git a/quantum/via.c b/quantum/via.c
index 643d7aa3c3..a4f7a450fc 100644
--- a/quantum/via.c
+++ b/quantum/via.c
@@ -436,18 +436,22 @@ void raw_hid_receive(uint8_t *data, uint8_t length) {
             dynamic_keymap_set_buffer(offset, size, &command_data[3]);
             break;
         }
-#ifdef ENCODER_MAP_ENABLE
         case id_dynamic_keymap_get_encoder: {
+#ifdef ENCODER_MAP_ENABLE
             uint16_t keycode = dynamic_keymap_get_encoder(command_data[0], command_data[1], command_data[2] != 0);
+#else
+            uint16_t keycode = KC_NO;
+#endif
             command_data[3]  = keycode >> 8;
             command_data[4]  = keycode & 0xFF;
             break;
         }
         case id_dynamic_keymap_set_encoder: {
+#ifdef ENCODER_MAP_ENABLE
             dynamic_keymap_set_encoder(command_data[0], command_data[1], command_data[2] != 0, (command_data[3] << 8) | command_data[4]);
+#endif
             break;
         }
-#endif
         default: {
             // The command ID is not known
             // Return the unhandled state
```

yoichi, 2025-03-07:
This issue occurs when ENCODER_MAP_ENABLE = no (default).

I don't know the revision from which cocot46plus_default_22_3 was built so I can't check the source code, but judging from the behavior, it seems that cocot46plus_default_22_3 was built with ENCODER_MAP_ENABLE = yes.

The latest firmware can also be built with ENCODER_MAP_ENABLE = yes by applying https://github.com/aki27kbd/qmk_firmware/pull/8 to reduce its size, so appling it and setting  ENCODER_MAP_ENABLE might be the solution of this problem.

yoichi, 2025-03-15:
I found there is a fixable issue in remap-keys.app (compare with usevia.app).

If we remove "lighting" element from https://github.com/aki27kbd/cocot46plus/blob/1704776d7bc9872e572fa5a30b7010e20b78713d/firmware/cocot46plus_via_rev.json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
then it can be loaded in from https://usevia.app/design (original cocot46plus_via_rev.json cannot be loaded there)

Connect cocot46plus with the latest firmware:
cocot46plus_default (January 20th 2025, 08:48:58 | SHA256: a6329de93551a9650175921a4e4310c94ec653e3f848a65c780e9f0843978262)
then we can customize keys except the rotary encoder. When I clicked the rotary encoder button, the error was handled correctly: "Your current firmware does not support rotary encoders."

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

So I think remap-keys.app can handle the error (detect the firmwared doesn't built with ENCODER_MAP_ENABLE = yes) too.

yoichi, 2025-03-31:
This issue was resolved by a fix to remap-keys: https://github.com/remap-keys/remap/pull/874

Closed 2025-03-31.

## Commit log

2022-06-03 update materials
2022-06-07 add middle plate data
2022-06-07 revise the link to middle plate
2022-06-23 update BOM
2022-07-07 add switch plate data
2022-07-11 add description for middle plate and firmware
2022-08-07 add the info for ver1.1 PCB
2022-10-17 add acrylic bottom plate data
    [cocot46plus_acrylic_bottom.dxf]
